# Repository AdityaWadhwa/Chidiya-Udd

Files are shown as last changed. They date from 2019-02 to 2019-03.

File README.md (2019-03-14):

# Chidiya-Udd
The title of the project “Chidiya udd” describes a popular Indian game which almost each Indian has played in their childhood. 

In the contemporary form, a person becomes a moderator and says the name of many objects which can either fly or they don’t and the players have to raise their finger in accordance with the object. 

This project replicates exactly the contemporary form but eliminating the need of a moderator which is fulfilled by the microcontroller. 
The project is developed under the guidance of Mr. D.V Gadre, CEDT lab in Netaji Subhas Institute of Technology (now, Netaji Subhas University of Technology). 

It was developed alongside my friend Sumiran Bhasin (https://github.com/sumiran14)

The microcontroller chosen is Texas Instruments low power device MSP430G2553.  

This project also interfaces two external SPI devices, the Graphics LCD and a flash memory; a speaker is used for the voice output.
The input from the player  is taken through a capacitive touch interface. 

As of now, it speaks only speaks in one language and only the name of the object. The next versions of the same project will have its own battery dependent power supply, better voice quality and more speed

The audio files are first downloaded (using Google translate) and converted and sampled at 8kHz and stored in 8 bit format(because human voice has maximum frequency of 4 kHZ and we sample it at at least twice that frequency) 
and saved in .wav format. Then using a software "WAVToCode" they are easily converted into c files. 
The data in the C files is really large so any microcontroller memory can’t fit all of that. 
So the data is sent through a python program from the PC to an Arduino and then written in external SPI Flash memory through Arduino.

When the data has to be played, MSP430 first fetches the data from SPI flash. 
That data decides the duty cycle of the PWM wave.The PWM wave is then sent as an input to a PAM IC and finally to a speaker to hear us the voice. As the data is sampled at 8Khz the duty cycle of the PWM wave has to be changed after every 1/8000th of a second i.e the next data is fetched from the external memory and played for 1/8000th of a second. 

The Graphics LCD is used to display the score. The code for the Graphics LCD is inspired by a blog by Rohit Gupta. 
Since timers are used for generating PWM, developing our own code for capacitive touch sensing was essential. 

In general, capacitive touch works on the basis of an oscillator with a capacitor. 
For a fixed period of time, the number of oscillations in that period would not vary much if the capacitance doesn’t change. 
Due to human interaction, capacitance of the circuit changes drastically and the variation in oscillations in the fixed time are different by a substantial amount causing us to detect a touch. 
MSP430G2553 have built in pin oscillators and by changing some values in registers we can make them enabled and use them as a clock source to one of the timers. 

The overall codeflow is that at the start the player has a fixed score of 9. The game doesn’t start as soon as the finger of the player isn’t on the touchplate and as one loses their score decreases. A random number generator generates a random number which calls a specific object. When the player has score 0 the reset button has to be pressed to play the game again.

Each code and EAGLE files for the same have been attached.

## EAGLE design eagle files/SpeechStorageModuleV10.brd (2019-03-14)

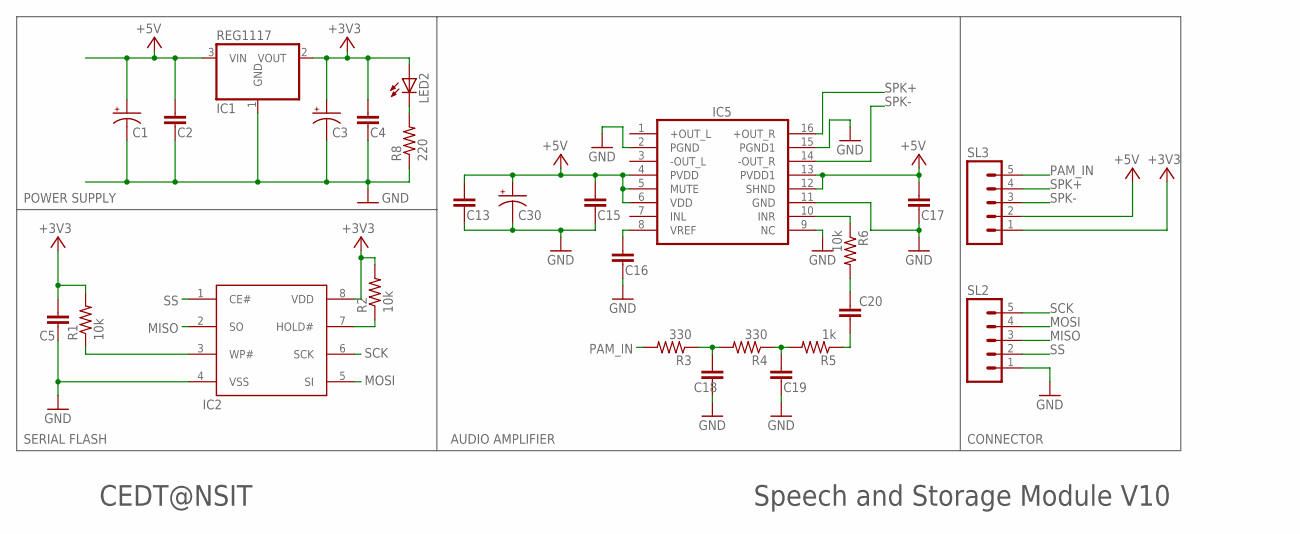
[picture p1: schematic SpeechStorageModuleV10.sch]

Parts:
C1, C3: 10u; C/6032-28R
C2, C4: 0.1uF; C1206
C5, C18: 0.1u; C0805
C13, C15, C17: 1uf; C1206
C16: 0.1uf; C1206
C19: 0.1uf; C0805
C20: 0.47uF; C0805
C30: 100u; C/6032-28R
IC1: REG1117; SOT223
IC2: SST25VF040B_SPI_FLASH; SOIC08
IC5: PAM8403; SOP-16
LED2: LED0805; CHIPLED_0805
R1, R2, R6: 10k; R0805
R3, R4: 330; R0805
R5: 1k; R0805
R8: 220; R0805
SL2, SL3: M05; 05P

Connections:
+3V3: C3.+, C4.2, C5.1, IC1.2 (VOUT), IC2.8 (VDD), LED2.A, R1.2, R2.2, SL3.1
+5V: C1.+, C2.2, C13.1, C15.2, C17.2, C30.+, IC1.3 (VIN), IC5.4 (PVDD), IC5.5 (MUTE), IC5.6 (VDD), IC5.12 (SHND), IC5.13 (PVDD1), SL3.2
GND: C1.-, C2.1, C3.-, C4.1, C5.2, C13.2, C15.1, C16.2, C17.1, C18.2, C19.2, C30.-, IC1.1 (GND), IC2.4 (VSS), IC5.2 (PGND), IC5.9 (NC), IC5.11 (GND), IC5.15 (PGND1), R8.1, SL2.1
MISO: IC2.2 (SO), SL2.3
MOSI: IC2.5 (SI), SL2.4
unnamed: IC2.7 (HOLD#), R2.1
unnamed: C18.1, R3.1, R4.2
unnamed: IC2.3 (WP#), R1.1
unnamed: C19.1, R4.1, R5.2
unnamed: C20.1, R5.1
unnamed: C20.2, R6.2
unnamed: LED2.C, R8.2
unnamed: IC5.10 (INR), R6.1
unnamed: C16.1, IC5.8 (VREF)
PAM_IN: R3.2, SL3.5
SCK: IC2.6 (SCK), SL2.5
SPK+: IC5.16 (+OUT_R), SL3.4
SPK-: IC5.14 (-OUT_R), SL3.3
SS: IC2.1 (CE#), SL2.2

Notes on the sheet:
POWER SUPPLY
SERIAL FLASH
CONNECTOR
AUDIO AMPLIFIER
Speech and Storage Module V10
CEDT@NSIT

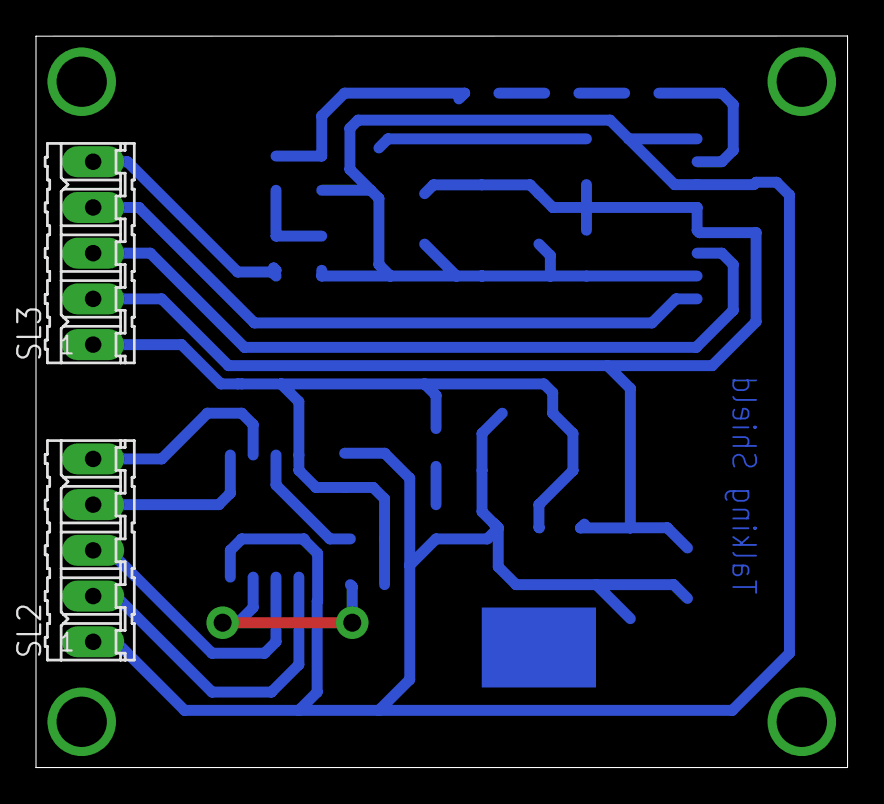
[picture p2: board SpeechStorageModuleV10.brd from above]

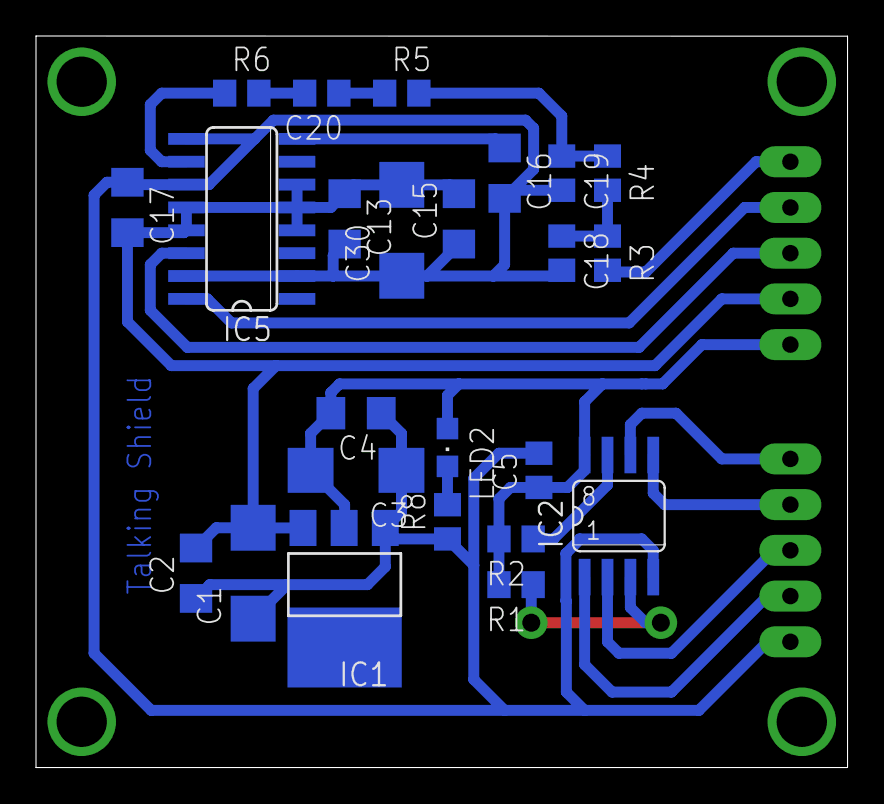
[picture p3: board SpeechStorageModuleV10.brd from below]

Board: 2 copper layers, 45.1 x 40.6 mm, 26 parts (24 on the bottom side), 19 nets.

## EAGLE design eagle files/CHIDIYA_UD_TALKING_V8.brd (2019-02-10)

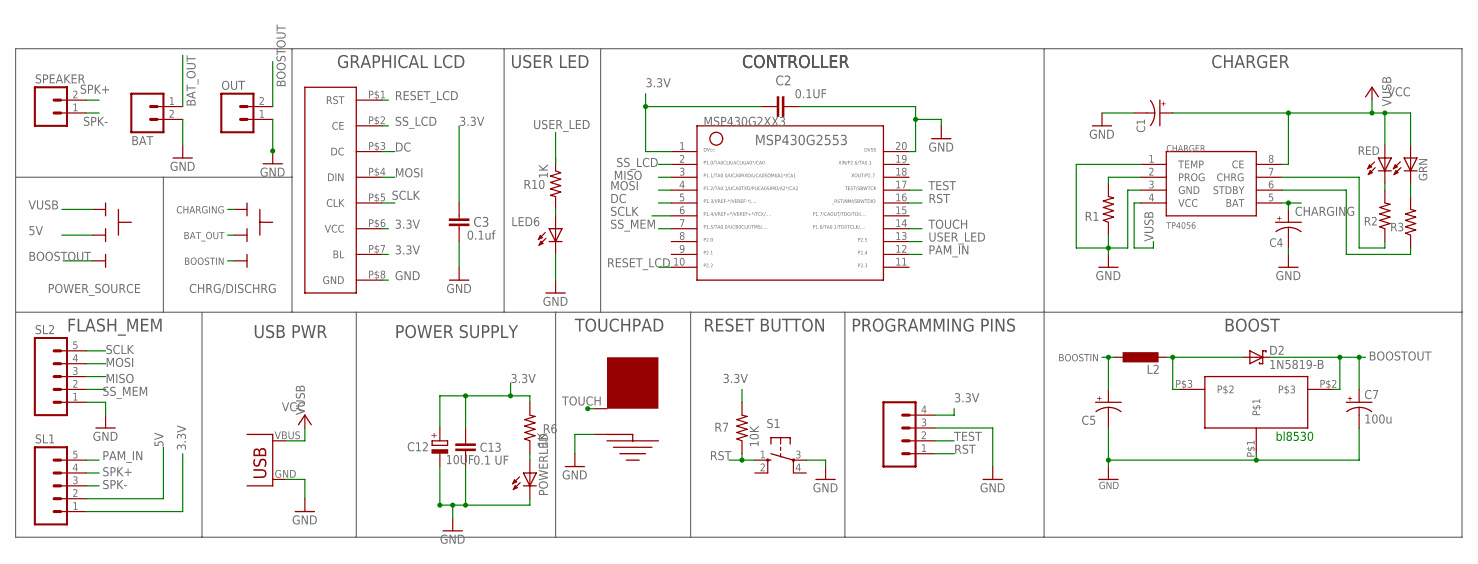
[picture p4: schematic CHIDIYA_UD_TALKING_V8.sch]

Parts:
BAT: M02; 02P
BOOST: BL8530_5V
C1, C4, C5: 10u; C/6032-28R
C2: 0.1UF; C050-025X075
C3: 0.1uf; C025-025X050
C7: 100u; C/6032-28R
C12: 10UF; E2,5-5
C13: 0.1 UF; C025-024X044
CHARGER: TP4056; SOP-8
CHRG/DISCHRG: SLIDESWITCH-BIG; BIGSWITCH
D2: 1N5819-B; DO41-7.6
GRN: LED3MM
L2: 47uH; L4532P
LED6: LED3MM
MSP430G2553: MSP430G2553DIP20; G2553-DIP20
OUT: M02; 02P
POWERLED: LED3MM
POWER_SOURCE: SLIDESWITCH-BIG; BIGSWITCH
PROGRAM: M04; 04P
R1: RESISTOR0805; R0805
R2, R3: 470; R0805
R6, R10: 1K; 0207/7
R7: 10K; 0207/7
RED: LED3MM
S1: 10-XX; B3F-10XX
SL1, SL2: M05; 05P
SPEAKER: M02; 02P
TOUCH1: TOUCHPAD-20MM
U$2: USB(POWER)
U$4: NOKIA_5110_LCD; NOKIA_5110_MODULE

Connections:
3.3V: C2.1, C3.1, C12.+, C13.1, MSP430G2553.1, PROGRAM.4, R6.2, R7.2, SL1.1, U$4.P$6 (VCC), U$4.P$7 (BL)
5V: POWER_SOURCE.2, SL1.2
BAT_OUT: BAT.1, CHRG/DISCHRG.2
BOOSTIN: C5.+, CHRG/DISCHRG.3, L2.1
BOOSTOUT: BOOST.P$2, C7.+, D2.C, OUT.2, POWER_SOURCE.3
CHARGING: C4.+, CHARGER.5 (BAT), CHRG/DISCHRG.1
DC: MSP430G2553.5, U$4.P$3 (DC)
GND: BAT.2, BOOST.P$1, C1.-, C2.2, C3.2, C4.-, C5.-, C7.-, C12.-, C13.2, CHARGER.1 (TEMP), CHARGER.3 (GND), LED6.K (C), MSP430G2553.20, OUT.1, POWERLED.K (C), PROGRAM.3, R1.1, S1.3, SL2.1, TOUCH1.GND, U$2.GND, U$4.P$8 (GND)
MISO: MSP430G2553.3, SL2.3
MOSI: MSP430G2553.4, SL2.4, U$4.P$4 (DIN)
unnamed: LED6.A, R10.2
unnamed: CHARGER.2 (PROG), R1.2
unnamed: CHARGER.7 (CHRG), R2.1
unnamed: CHARGER.6 (STDBY), R3.1
unnamed: R2.2, RED.K (C)
unnamed: BOOST.P$3, D2.A, L2.2
unnamed: POWERLED.A, R6.1
unnamed: GRN.K (C), R3.2
PAM_IN: MSP430G2553.12, SL1.5
RESET_LCD: MSP430G2553.10, U$4.P$1 (RST)
RST: MSP430G2553.16, PROGRAM.1, R7.1, S1.1 (S)
SCLK: MSP430G2553.6, SL2.5, U$4.P$5 (CLK)
SPK+: SL1.4, SPEAKER.2
SPK-: SL1.3, SPEAKER.1
SS_LCD: MSP430G2553.2, U$4.P$2 (CE)
SS_MEM: MSP430G2553.7, SL2.2
TEST: MSP430G2553.17, PROGRAM.2
TOUCH: MSP430G2553.14, TOUCH1.TOUCH
USER_LED: MSP430G2553.13, R10.1
VUSB: C1.+, CHARGER.4 (VCC), CHARGER.8 (CE), GRN.A, POWER_SOURCE.1, RED.A, U$2.VBUS (VCC)

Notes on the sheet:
GRAPHICAL LCD
USER LED
CONTROLLER
FLASH_MEM
POWER SUPPLY
TOUCHPAD
RESET BUTTON
PROGRAMMING PINS
bl8530
USB PWR
CHARGER
BOOST

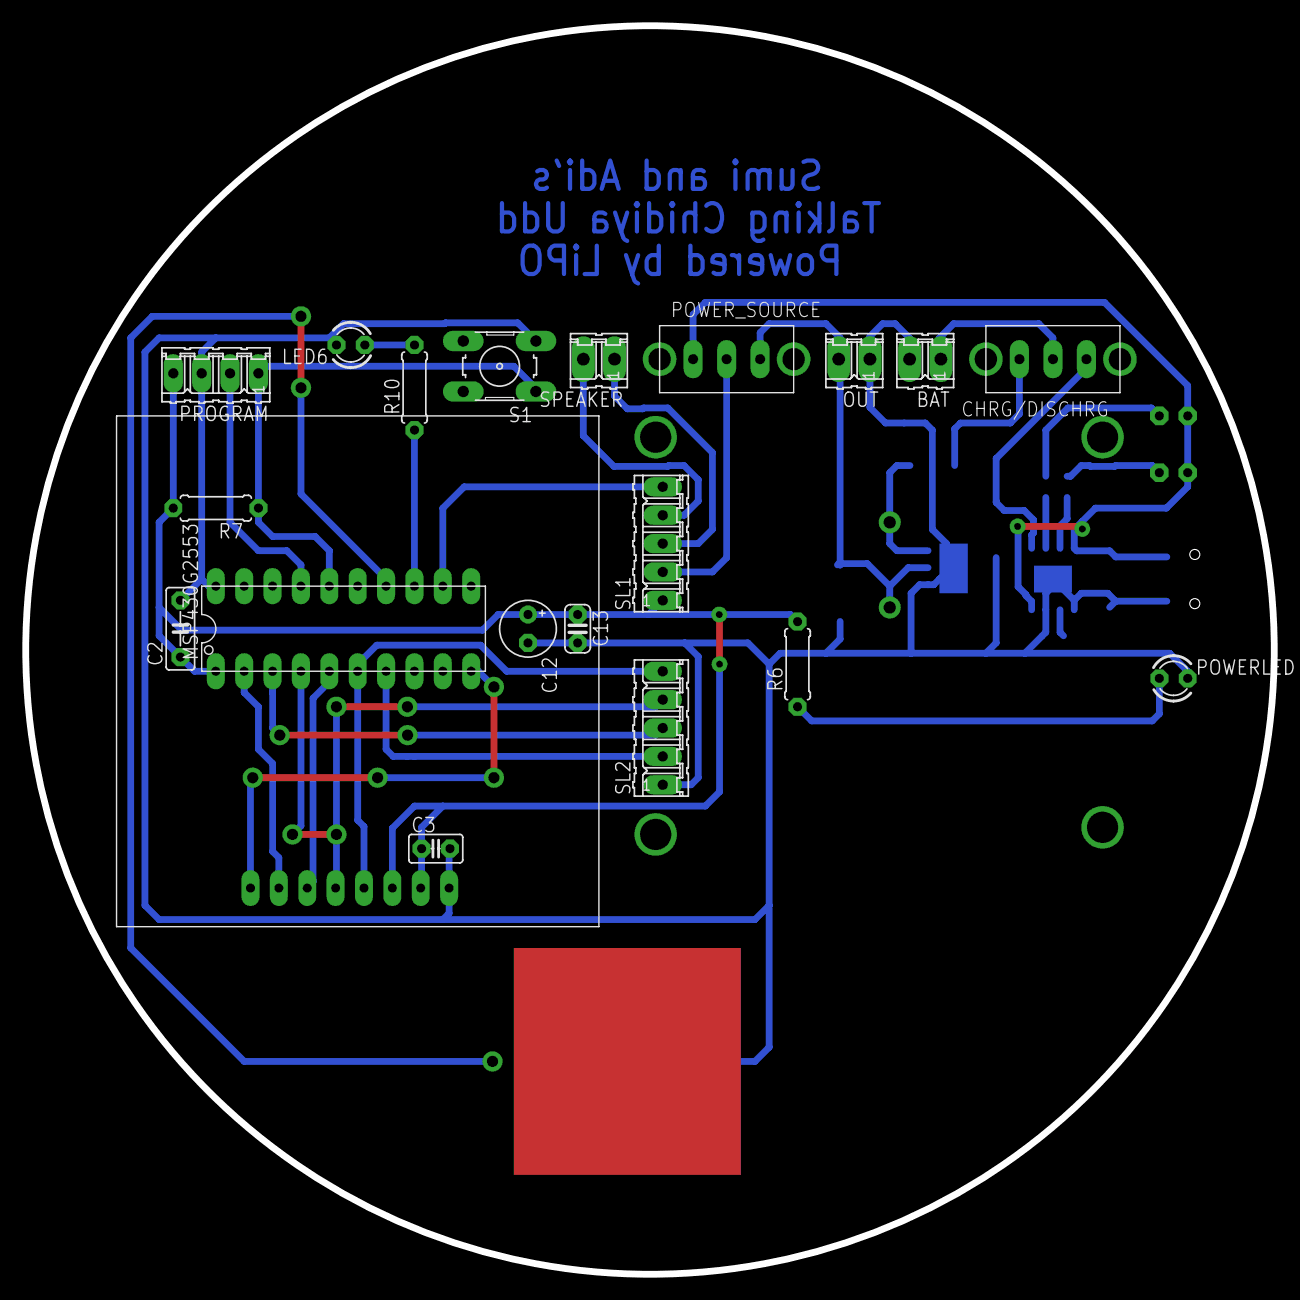
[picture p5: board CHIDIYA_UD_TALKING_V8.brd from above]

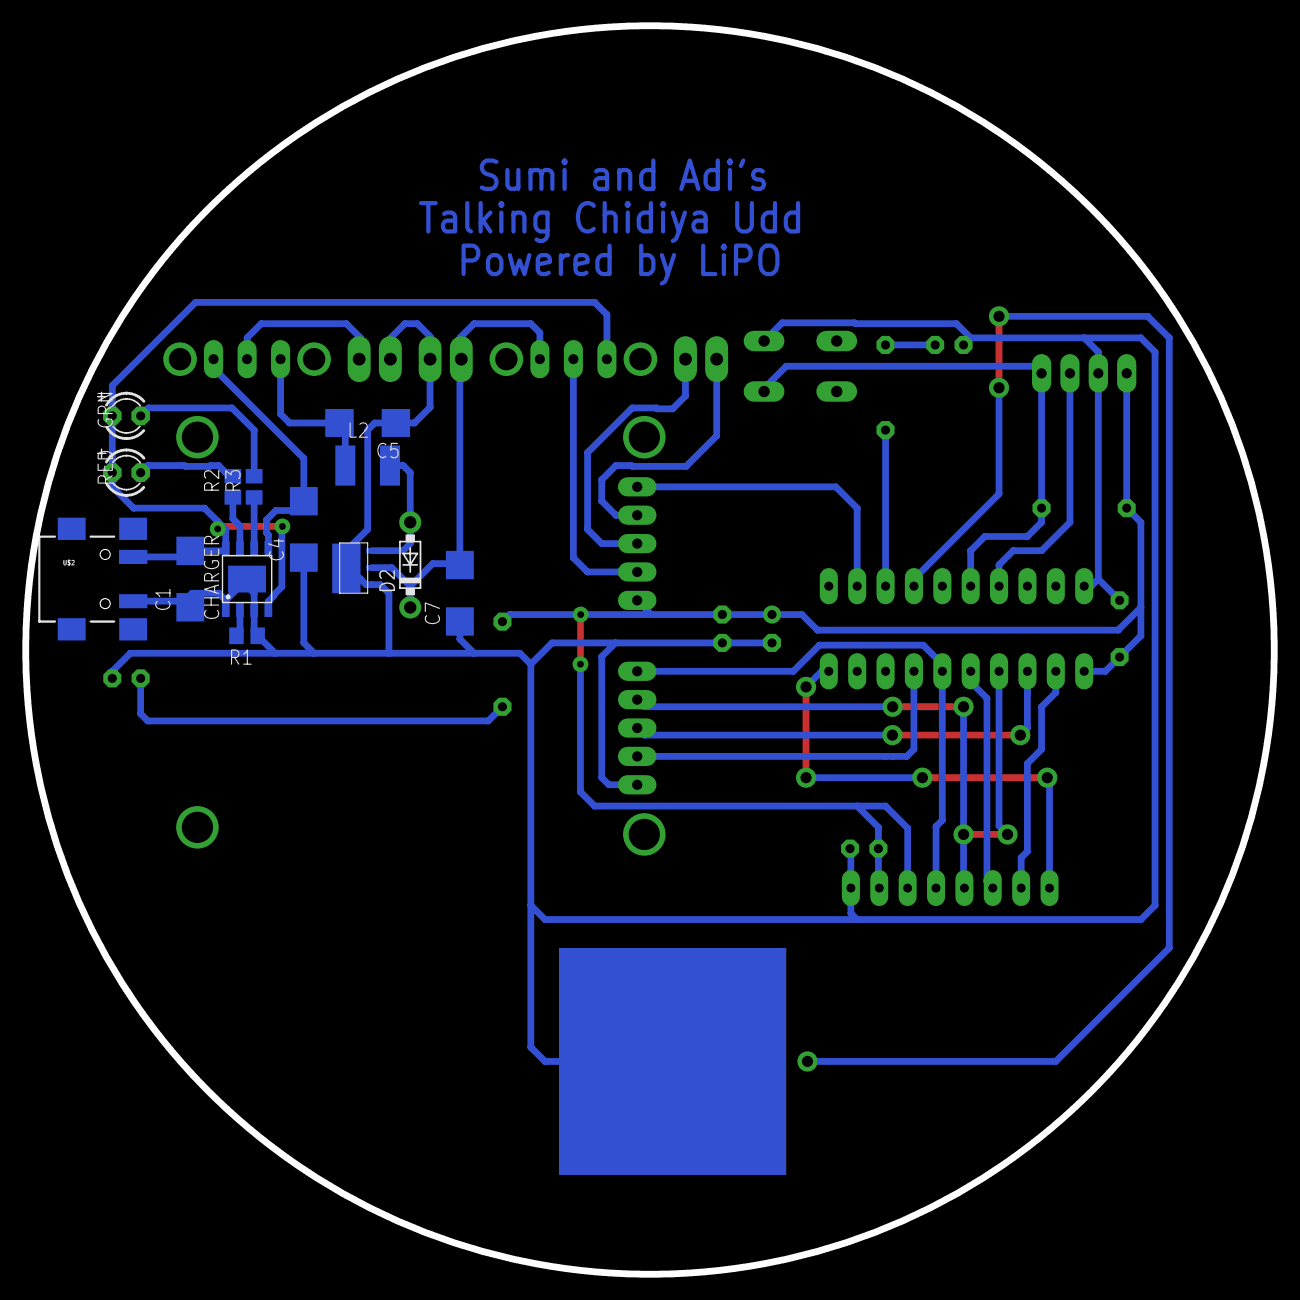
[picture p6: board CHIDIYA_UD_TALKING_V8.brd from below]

Board: 2 copper layers, 111.8 x 111.8 mm, 35 parts (14 on the bottom side), 30 nets.

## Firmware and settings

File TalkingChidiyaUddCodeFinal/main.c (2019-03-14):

#include <msp430.h>
#include <PCD8544.h>
#include <stdbool.h>
#include <inttypes.h>
#include <rand.h>

#define WRITE_ENABLE       0x06
#define WRITE_DISABLE      0x04
#define CHIP_ERASE         0xc7
#define READ_STATUS_REG_1  0x05
#define READ_DATA          0x03
#define PAGE_PROGRAM       0x02
#define JEDEC_ID           0x9F
#define BLOCK_ERASE        0xD8

#define abs(x) ((x>0)?(x):(-x))

#define NOP         0b00000000
#define FunctionSet 0b00100000 //0  0  1  0  0 PD  V  H
#define DispControl 0b00001100 //0  0  0  0  1  D  0  E
#define SetYAddress 0b01000000 //0  1  0  0  0 Y2 Y1 Y0
#define SetXAddress 0b10000000 //1 X6 X5 X4 X3 X2 X1 X0
#define SS_LCD BIT0
#define SS_MEM BIT5
#define DC     BIT3

#define LCD5110_RES_PIN     BIT2
#define LCD5110_SCLK_PIN    BIT4
#define LCD5110_DN_PIN      BIT2
#define LCD5110_SCE_PIN     BIT0
#define LCD5110_DC_PIN      BIT3
#define LCD5110_SELECT      P1OUT &= ~LCD5110_SCE_PIN
#define LCD5110_DESELECT    P1OUT |= LCD5110_SCE_PIN
#define LCD5110_SET_COMMAND P1OUT &= ~LCD5110_DC_PIN
#define LCD5110_SET_DATA    P1OUT |= LCD5110_DC_PIN
#define LCD5110_COMMAND     0
#define LCD5110_DATA        1

#define SPI_MSB_FIRST UCA0CTL0 |= UCMSB // or UCA0CTL0 |= UCMSB (USCIA) or USICTL0 &= ~USILSB (USI)
#define SPI_LSB_FIRST UCA0CTL0 &= ~UCMSB // or UCA0CTL0 &= ~UCMSB or USICTL0 |= USILSB (USI)

#define UserLED BIT5    //P2.5 is connected to User LED

uint8_t ManID = 0,memoryType = 0,capacity = 0;
uint32_t addr = 0x00000000,in=0;
unsigned int base_cnt, meas_cnt;
int delta_cnt, k;
uint8_t i,val;
int pt;

//                        one       two         three       aeroplane       batak       bus         chidiya    maina       naav        patang       Table      tota        train       GAMEOVER    PlaceFinger Game
uint32_t startAddr[16] = {0         ,11904      ,23808      ,36864          ,55680      ,70656      ,82560     ,116352     ,130560     ,142848     ,199680     ,241920     ,256128     ,98304      ,156672     ,212736}       ; //Stores starting addresses of all audio files
uint32_t endinAddr[16] = {11904     ,23808      ,36864      ,55680          ,70656      ,82560      ,98304     ,130560     ,142848     ,156672     ,212736     ,256128     ,269184     ,116352     ,199680     ,241920}       ; //Stores ending addresses of all audio files
int fly[10]            = {                                   1              ,1          ,0          ,1         ,1          ,0          ,1          ,0          ,1          ,0     }       ; //Stores whether the audio at that index fly or not
int index;                //= 1;

unsigned char transmit(unsigned char data)
{
    while (!(IFG2 & UCA0TXIFG));
    UCA0TXBUF = data;
    while (!(IFG2 & UCA0RXIFG)); // As soon as the transmit is complete the SPIF bit is set in the SPSR register of the spi module. The while condition is turned to 0 as soon as this happens
    return (UCA0RXBUF);
}

void unbusy(void)
{
    P1OUT |= BIT5;
    P1OUT &= ~BIT5;
    transmit(READ_STATUS_REG_1);
    while (transmit(0x00) != 0x00)
    {
    };
    while (!(IFG2 & UCA0TXIFG));
    P1OUT |= BIT5;
}

void timer_init()
{
    //set WDT for time keeping purpose
    //need an interrupt every 1/8000 of a second,i.e. when count reaches 2000
    WDTCTL = WDT_MDLY_0_5;                      // WDT 1/32000s, SMCLK, interval timer
    IE1 |= WDTIE;                               // Enable WDT interrupt


    //Timer A0 sourced by pin oscillator
    TA0CTL   = TASSEL_3 + MC_2 + TACLR;       // TACLK, cont mode
    TA0CCTL1 = CM_3 + CCIS_2 +CAP;               // Pos&Neg,GND,Cap


    /*Configure Ports for relaxation oscillator*/
    /*The P1SEL2 register allows Timer_A to receive it's clock from a GPIO*/
    /*See the Application Information section of the device datasheet for info*/
    P1DIR  &= ~BIT6;                        // P1.6 is the input used here
    P1SEL  &= ~BIT6;
    P1SEL2 |=  BIT6;


    //set timer 1 to drive pwm

    TA1CCR0 = 256;          //8 bit PWM mode
    TA1CCR2 = 127;          //initial width

    TA1CTL |= TASSEL_2;     //select SMCLK as source
    TA1CTL |= TACLR;        //clear
    TA1CTL |= MC_1;         //up mode

    TA1CCTL2 |= OUTMOD_7;   //reset set mode

}

void clockInit()
{
    BCSCTL1 |= CALBC1_16MHZ;                              // Set DCO to 1MHz
    DCOCTL  |= CALDCO_16MHZ;
}

void spi_init()
{
    P1DIR |= BIT5;
    P1OUT |= BIT5;

    P1DIR |= SS_LCD;                                      //SS of GLCD
    P1OUT |= SS_LCD;

    P1DIR |= DC;                                         //DC of GLCD
    P1OUT &=~DC;

    P1SEL |= BIT1 + BIT2 + BIT4;                        //P1.4 -> CLK , P1.2 -> SIMO, P1.1 -> SOMI
    P1SEL2|= BIT1 + BIT2 + BIT4;                        //P1.4 -> CLK , P1.2 -> SIMO, P1.1 -> SOMI

    UCA0CTL1 |= UCSWRST;                                // Hold USCI in reset state
    UCA0CTL0 |= UCCKPH + UCMST + UCSYNC + UCMSB;        // 3-pin, 8-bit, SPI Master
    UCA0CTL0 &= ~UCCKPL;
    UCA0CTL1 |= UCSSEL_2;                               // Clock -> SMCLK
    UCA0BR0 = 2;                                     // SPI CLK -> SMCLK/2
    UCA0BR1 = 0;
    UCA0MCTL = 0;
    UCA0CTL1 &= ~UCSWRST;
}

void measure_count()
{
    TA0CTL |= TACLR;                        // Clear Timer_A TAR

    __delay_cycles(500);

    TA0CCTL1 ^= CCIS0;                      // Create SW capture of CCR1
    TA0CCTL1 ^= CCIS0;                      // Create SW capture of CCR1
    meas_cnt = TACCR1;                      // Save result
}

void writeToLCD(unsigned char dataCommand, unsigned char data)
{
//    __disable_interrupt();
    __delay_cycles(10000);
    BCSCTL1 = CALBC1_1MHZ;                  // Set DCO to 1MHz
    DCOCTL  = CALDCO_1MHZ;
    UCA0CTL1 |= UCSWRST;                    // Hold USCI in reset state
    UCA0BR0 = 1;                            // SPI CLK -> SMCLK
    UCA0BR1 = 0;                            // SPI CLK -> SMCLK
    UCA0CTL1 &= ~UCSWRST;

    __delay_cycles(10000);

    LCD5110_SELECT;

    if(dataCommand)
    {
        LCD5110_SET_DATA;
    }
    else
    {
        LCD5110_SET_COMMAND;
    }

    UCA0TXBUF = data;
    while(!(IFG2 & UCA0TXIFG));

    LCD5110_DESELECT;

    __delay_cycles(10000);

    BCSCTL1 = CALBC1_16MHZ;                 // Set DCO to 16MHz
    DCOCTL  = CALDCO_16MHZ;
    UCA0CTL1 |= UCSWRST;                    // Hold USCI in reset state
    UCA0BR0 = 2;                            // SPI CLK -> SMCLK/2
    UCA0BR1 = 0;                            // SPI CLK -> SMCLK
    UCA0CTL1 &= ~UCSWRST;
    __delay_cycles(10000);
//    __enable_interrupt();
}

void writeCharToLCD(char c)
{
    unsigned char i;
    for(i = 0; i < 5; i++)
    {
        writeToLCD(LCD5110_DATA, font[c - 0x20][i]);
    }
    writeToLCD(LCD5110_DATA, 0);
}

void writeStringToLCD(const char *string)
{
    while(*string)
    {
        writeCharToLCD(*string++);
    }
}

void writeBlockToLCD(char *byte, unsigned char length)
{
    unsigned char c = 0;
    while(c < length)
    {
        writeToLCD(LCD5110_DATA, *byte++);
        c++;
    }
}

void writeGraphicToLCD(char *byte, unsigned char transform)
{
    int c = 0;
    char block[8];

    if(transform & FLIP_V)
    {
        SPI_LSB_FIRST;
    }
    if(transform & ROTATE)
    {
        c = 1;
        while(c != 0)
        {
            (*byte & 0x01) ? (block[7] |= c) : (block[7] &= ~c);
            (*byte & 0x02) ? (block[6] |= c) : (block[6] &= ~c);
            (*byte & 0x04) ? (block[5] |= c) : (block[5] &= ~c);
            (*byte & 0x08) ? (block[4] |= c) : (block[4] &= ~c);
            (*byte & 0x10) ? (block[3] |= c) : (block[3] &= ~c);
            (*byte & 0x20) ? (block[2] |= c) : (block[2] &= ~c);
            (*byte & 0x40) ? (block[1] |= c) : (block[1] &= ~c);
            (*byte & 0x80) ? (block[0] |= c) : (block[0] &= ~c);
            *byte++;
            c <<= 1;
        }
    } else
    {
        while(c < 8) {
            block[c++] = *byte++;
        }
    }

    if(transform & FLIP_H)
    {
        c = 7;
        while(c > -1)
        {
            writeToLCD(LCD5110_DATA, block[c--]);
        }
    } else
    {
        c = 0;
        while(c < 8)
        {
            writeToLCD(LCD5110_DATA, block[c++]);
        }
    }
    SPI_MSB_FIRST;
}
void setAddr(unsigned char xAddr, unsigned char yAddr)
{
    writeToLCD(LCD5110_COMMAND, PCD8544_SETXADDR | xAddr);
    writeToLCD(LCD5110_COMMAND, PCD8544_SETYADDR | yAddr);
}

void clearLCD()
{
    setAddr(0,0);
    int c = 0;
    while(c < PCD8544_MAXBYTES)
    {
        writeToLCD(LCD5110_DATA, 0);
        c++;
    }
    setAddr(0, 0);
}

void clearBank(unsigned char bank)
{
    setAddr(0, bank);
    int c = 0;
    while(c < PCD8544_HPIXELS)
    {
        writeToLCD(LCD5110_DATA, 0);
        c++;
    }
    setAddr(0, bank);
}

void initLCD()
{
    writeToLCD(LCD5110_COMMAND, PCD8544_FUNCTIONSET | PCD8544_EXTENDEDINSTRUCTION);
    writeToLCD(LCD5110_COMMAND, PCD8544_SETVOP | 0x3F);
    writeToLCD(LCD5110_COMMAND, PCD8544_SETTEMP | 0x02);
    writeToLCD(LCD5110_COMMAND, PCD8544_SETBIAS | 0x03);
    writeToLCD(LCD5110_COMMAND, PCD8544_FUNCTIONSET);
    writeToLCD(LCD5110_COMMAND, PCD8544_DISPLAYCONTROL | PCD8544_DISPLAYNORMAL);

}

void placeFinger()
{
    addr  = startAddr[14];       //play audio of PlaceFinger
    __enable_interrupt();

    while(1)
    {
        measure_count();
        delta_cnt = meas_cnt - base_cnt;

        if(abs(delta_cnt) > 40)
        {
            __disable_interrupt();
            index = rand();
            index = abs(index%9) + 3;
            addr  = startAddr[index];
            __enable_interrupt();

            break;
        }
        else if(addr  == endinAddr[14])
        {
            addr  = startAddr[14];                      //keeps speaking "place finger" until the user does so
        }
    }
}

int main(void)
{
    WDTCTL = WDTPW | WDTHOLD;                           // Stop watchdog timer

    clockInit();
    __delay_cycles(100);
    spi_init();
    __delay_cycles(100);
    timer_init();
    __delay_cycles(100);

    P2DIR |= UserLED;

    P2DIR |= BIT2;                           // Reset the LCD
    P2OUT &=~BIT2;
    __delay_cycles(4000);
    P2OUT |= BIT2;
    __delay_cycles(4000);

    P1OUT |= BIT5;
    P1OUT &= ~BIT5;

    transmit(JEDEC_ID);
    ManID  = transmit(0);
    memoryType = transmit(0);
    capacity = transmit(0);

    P1OUT |= BIT5;

    initLCD();
    __delay_cycles(100);

    for(i=0;i<25;i++)
    {
        measure_count();
        base_cnt = (meas_cnt+base_cnt)/2;
    }

    i = 0x39;                               //ascii for '9'

    clearBank(0);
    writeStringToLCD(" Chidiya Udd ");
    clearBank(1);
    writeStringToLCD(" with MSP430 ");
    clearBank(2);
    writeStringToLCD("Score : ");
    setAddr(45,2);
    writeCharToLCD(i);

    P2DIR |= BIT4;          //P2.4 is connected to input of PAM
    P2SEL |= BIT4;
    P2SEL2&=~BIT4;

    __enable_interrupt();

    placeFinger();

    addr  = startAddr[15];      //The Game will begin in
    while(addr!=endinAddr[15]);

    addr  = startAddr[2];       //Three
    while(addr!=endinAddr[2]);

    addr  = startAddr[1];       //Two
    while(addr!=endinAddr[1]);

    addr  = startAddr[0];       //One
    while(addr!=endinAddr[0]);

    index = rand();
    index = abs(index%9) + 3;
    addr  = startAddr[index];

    while(1)
    {
        if(addr==endinAddr[index])                  //if end of current audio is reached play next audio
        {
            __disable_interrupt();

            if(fly[index-3]==1)                       //current audio being played flies
            {                                       //audio has ended but user didn't lift finger
                measure_count();
                delta_cnt = meas_cnt - base_cnt;

                if(abs(delta_cnt) > 40)
                {
                    i--;
                    setAddr(45,2);
                    writeCharToLCD(i);
                }
            }
            else
            {
                measure_count();
                delta_cnt = meas_cnt - base_cnt;

                if(abs(delta_cnt) < 40)
                {
                    i--;
                    setAddr(45,2);
                    writeCharToLCD(i);
                }
            }
            __delay_cycles(64000000);       //stops for 5sec
            placeFinger();
        }
        if(i==0x30)
        {
            while(1)
            {
                addr  = startAddr[13];      //audio for Game Over
                while(addr!=endinAddr[13]);
                __disable_interrupt();
                __delay_cycles(32000000);       //stops for 2sec
                __enable_interrupt();
            }
        }
    }
}


// Watchdog Timer interrupt service routine
#if defined(__TI_COMPILER_VERSION__) || defined(__IAR_SYSTEMS_ICC__)
#pragma vector=WDT_VECTOR
__interrupt void watchdog_timer(void)
#elif defined(__GNUC__)
void __attribute__ ((interrupt(WDT_VECTOR))) watchdog_timer (void)
#else
#error Compiler not supported!
#endif
{
    pt++;
    if(pt==2)
    {
        //coming into this indicates 1/8000 of a second have passed
        //so read the next byte and set the new pulse width
        P1OUT &= ~BIT5;

        transmit(READ_DATA);
        transmit( (addr&0x00FF0000) >> 16);
        transmit( (addr&0x0000FF00) >>  8);
        transmit( (addr&0x000000FF));

        val = transmit(0);

        TA1CCR2 = val;

        P1OUT |= BIT5;

        addr++;
        pt=0;
    }
}

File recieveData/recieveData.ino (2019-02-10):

#define LED 8
#include<SPIMemory.h>

SPIFlash flash;
//SPIFlash flash;
volatile uint64_t add;
int i;
volatile uint8_t value;

void setup()
{
  add = 0;
  Serial.begin(57600);
  pinMode(LED,OUTPUT);
  digitalWrite(LED,HIGH);
  while(!Serial);
  delay(50);
  digitalWrite(LED,LOW);
  flash.begin();
  flash.eraseChip();
  //int number = 0;
}

void loop()
{
  while(Serial.available()==0);
  String value = Serial.readStringUntil('\n');
  char t = Serial.read();
  //Serial.setTimeout(0.01);
  int val = value.toInt();
  flash.writeByte(add, val);
  add++;
}

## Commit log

2019-02-10 SPI flash writing through python
2019-02-10 Eagle files
    [CHIDIYA_UD_TALKING_V8.brd, CHIDIYA_UD_TALKING_V8.sch]
2019-02-10 Arduino code

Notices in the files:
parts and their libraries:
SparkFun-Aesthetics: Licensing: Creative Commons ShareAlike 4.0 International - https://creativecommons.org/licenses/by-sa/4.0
